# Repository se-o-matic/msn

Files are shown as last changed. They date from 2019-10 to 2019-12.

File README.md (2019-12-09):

# MSN

## MySensors Nodes
Hardware and software for MySensors.org IOT network.
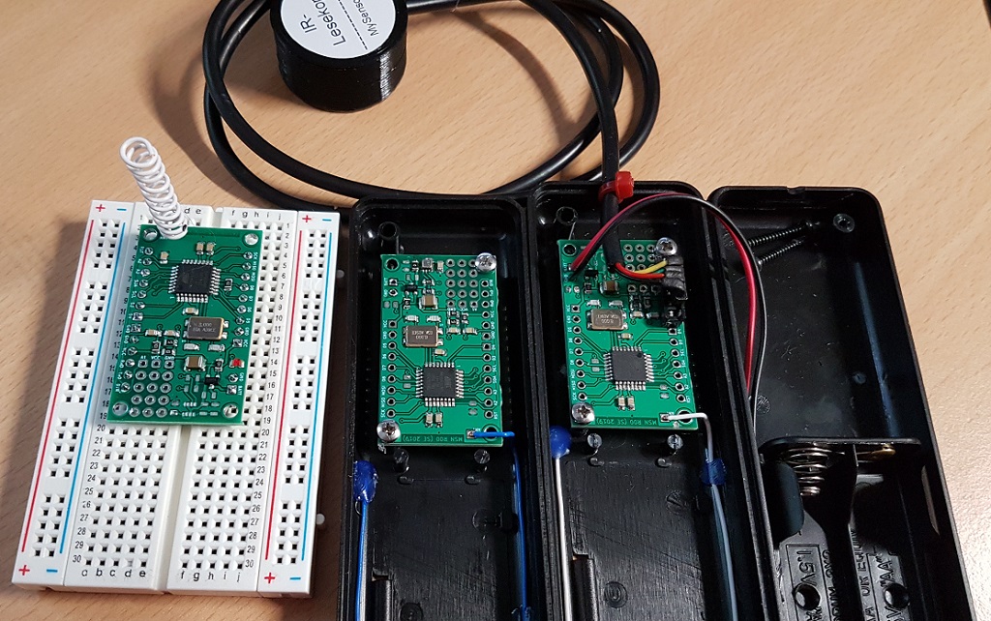
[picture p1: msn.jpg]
Different MSN sensor nodes

The MSN PCB can be used for different node types. The minimal assembly consists of a Mega328P microcontroller (as seen on many Arduinos), a RFM69CW rf module with 868 or 433 MHz and some little stuff for reverse protection and battery monitoring.

With different assembly options, this PCB can be used for:
  * Temperature, humidity and pressure measurements (With BME280 assembled)
  * Sensor above with additional light level (with extra BH1750 on the proto field)
  * Cheap temperature measurement (With DS18B20 assembled on the small proto field)
  * IR-reader for digital Power meter (with external IR Head connected to UART)
  * Prototyping on Breadboards with soldered pin header

The PCB features also
  * ISP pins are connected to the pin header for flashing the bootloader
  * Arduino pro mini compatible pin header for connecting a UART-board
  * Optional LED for example for active transmission
  * Mounting holes for fitting in the “Strapubox 6090” case
  * A snap off proto board, which fit under or on top of the MSN PCB.

## V0.1
Software tested on breadboards. Hardware not tested, because the boards are still in production.

## V1.0
TBD Software modified to run on MSN PCB. Different improvements, like other libraries for enable power savings of the sensors.

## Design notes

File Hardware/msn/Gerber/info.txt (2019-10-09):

MSN_Gerber.zip
--------------
gerber files for elecrow.com

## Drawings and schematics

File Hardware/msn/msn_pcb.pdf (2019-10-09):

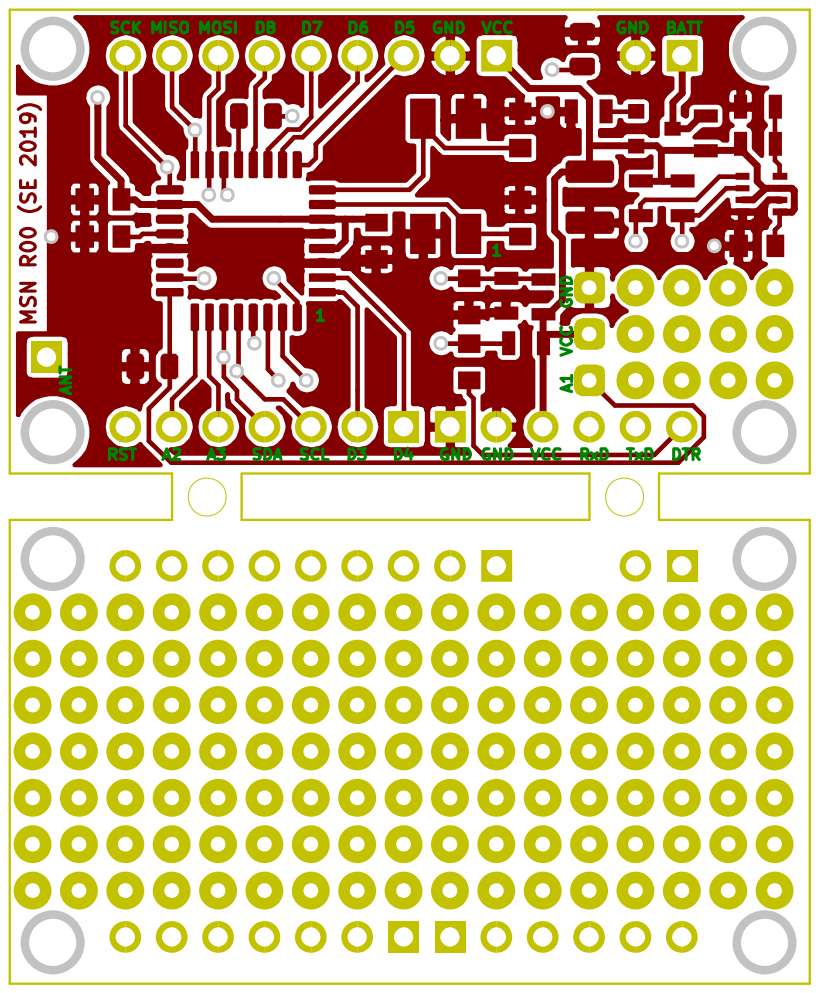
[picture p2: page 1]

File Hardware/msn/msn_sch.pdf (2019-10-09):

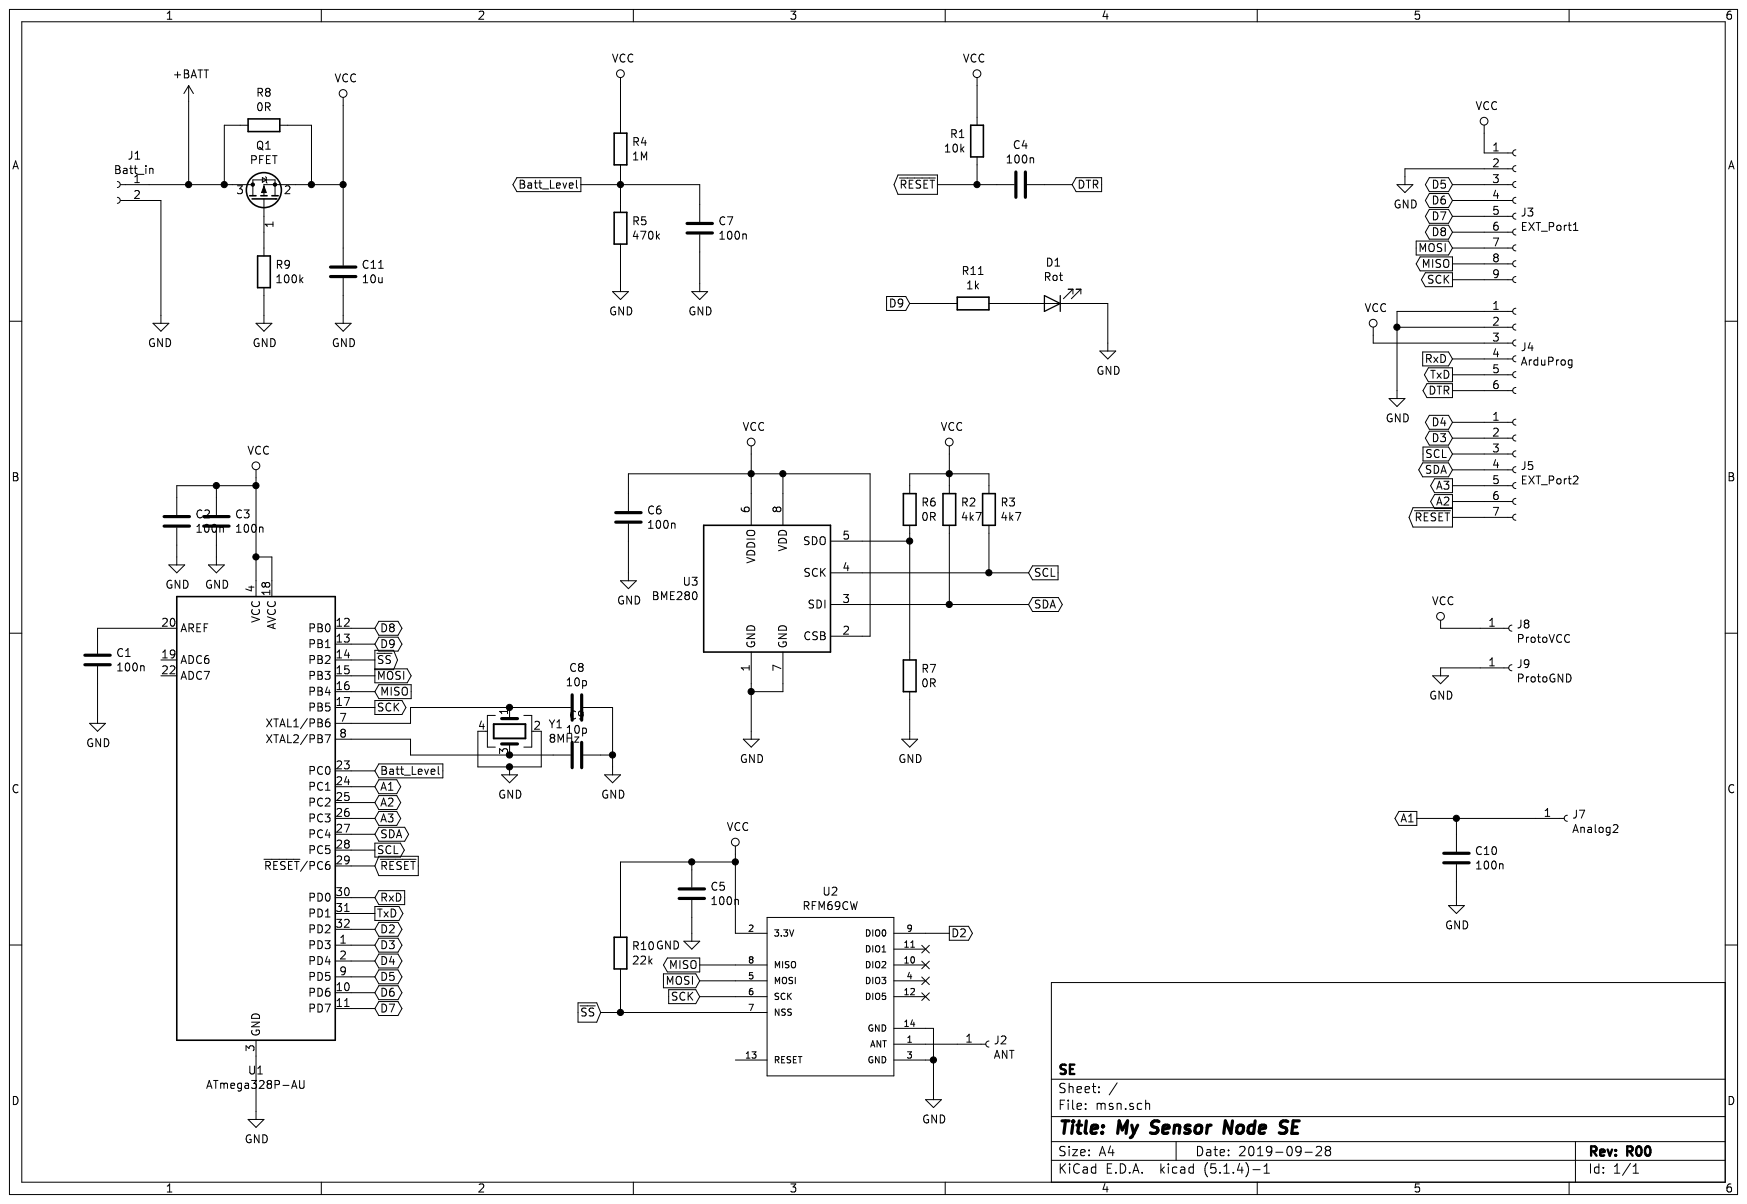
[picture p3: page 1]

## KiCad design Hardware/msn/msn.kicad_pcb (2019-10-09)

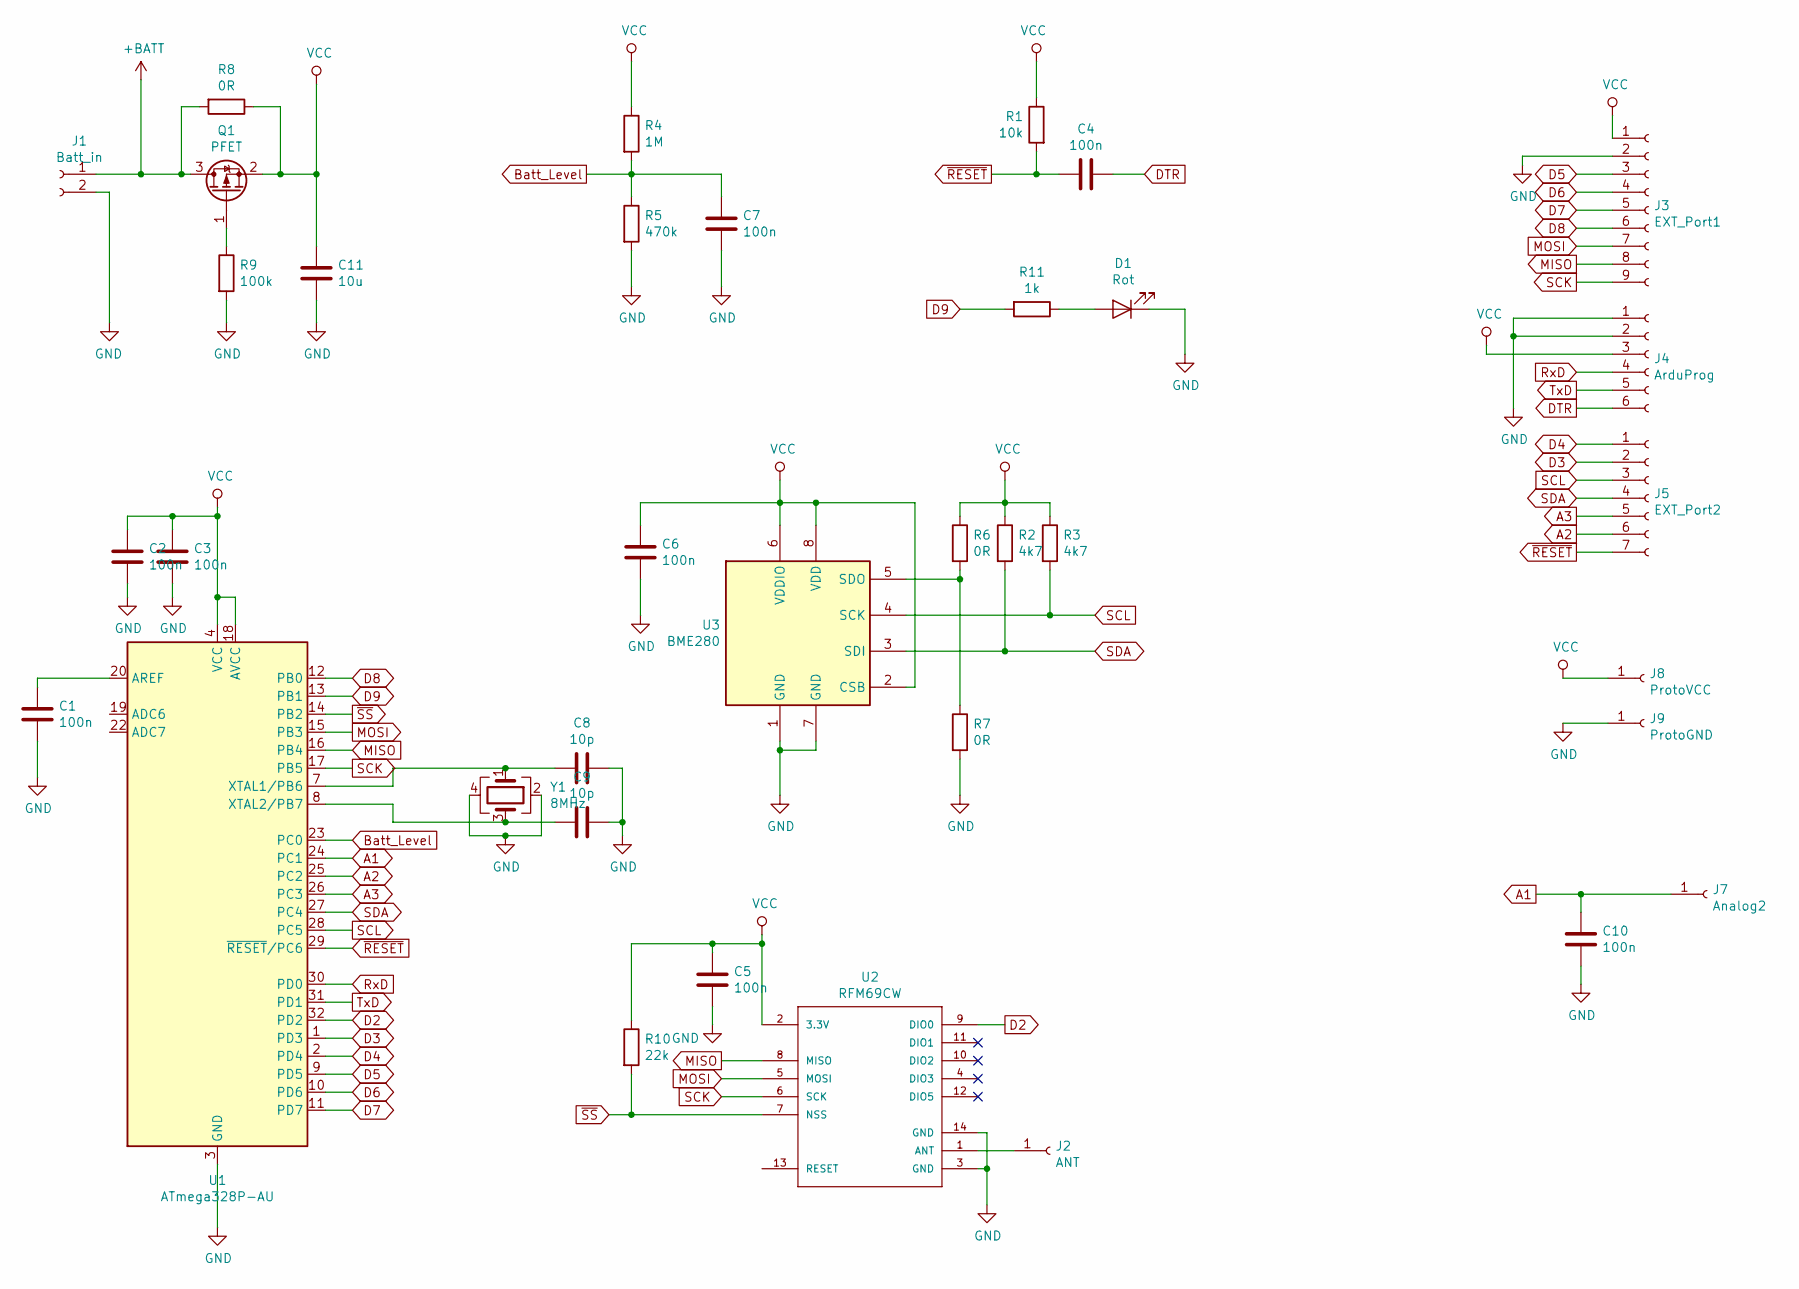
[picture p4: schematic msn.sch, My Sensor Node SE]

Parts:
C1, C2, C3, C4, C5, C6, C7, C10: 100n; C_0805_2012Metric
C8, C9: 10p; C_0805_2012Metric
C11: 10u; C_1210_3225Metric
D1: Rot; LED_0805_2012Metric
J1: Batt_in; Pin_Header_Straight_1x02_Pitch2.54mm
J2: ANT; Pin_Header_Straight_1x01_Pitch2.54mm
J3: EXT_Port1; PinHeader_1x09_P2.54mm_Vertical
J4: ArduProg; PinHeader_1x06_P2.54mm_Vertical
J5: EXT_Port2; PinHeader_1x07_P2.54mm_Vertical
J7: Analog2; PinHeader_1x01_P2.54mm_Vertical
J8: ProtoVCC; PinHeader_1x01_P2.54mm_Vertical
J9: ProtoGND; PinHeader_1x01_P2.54mm_Vertical
Q1: PFET; SOT-23
R1: 10k; R_0805_2012Metric
R2, R3: 4k7; R_0805_2012Metric
R4: 1M; R_0805_2012Metric
R5: 470k; R_0805_2012Metric
R6, R7, R8: 0R; R_0805_2012Metric
R9: 100k; R_0805_2012Metric
R10: 22k; R_0805_2012Metric
R11: 1k; R_0805_2012Metric
U1: ATmega328P-AU; LQFP-32_7x7mm_P0.8mm
U2: RFM69CW; RFM69CW-XXXS2
U3: BME280; Bosch_LGA-8_2.5x2.5mm_P0.65mm_ClockwisePinNumbering
Y1: 8MHz; Crystal_SMD_EuroQuartz_MQ-4pin_7.0x5.0mm

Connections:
+BATT: J1.1, Q1.3 (D), R8.2
A1: C10.1, J7.1, U1.24 (PC1)
A2: J5.6, U1.25 (PC2)
A3: J5.5, U1.26 (PC3)
Batt_Level: C7.1, R4.2, R5.1, U1.23 (PC0)
D2: U1.32 (PD2), U2.9 (DIO0)
D3: J5.2, U1.1 (PD3)
D4: J5.1, U1.2 (PD4)
D5: J3.3, U1.9 (PD5)
D6: J3.4, U1.10 (PD6)
D7: J3.5, U1.11 (PD7)
D8: J3.6, U1.12 (PB0)
D9: R11.2, U1.13 (PB1)
DTR: C4.2, J4.6
GND: C1.2, C2.2, C3.2, C5.2, C6.2, C7.2, C8.1, C9.1, C10.2, C11.2, D1.1 (K), J1.2, J3.2, J4.1, J4.2, J9.1, R5.2, R7.2, R9.2, U1.3 (GND), U1.5 (GND), U1.21 (GND), U2.3 (GND), U2.14 (GND), U3.1 (GND), U3.7 (GND), Y1.2, Y1.4
MISO: J3.8, U1.16 (PB4), U2.8 (MISO)
MOSI: J3.7, U1.15 (PB3), U2.5 (MOSI)
unnamed: C1.1, U1.20 (AREF)
unnamed: C8.2, U1.7 (XTAL1/PB6), Y1.1
unnamed: C9.2, U1.8 (XTAL2/PB7), Y1.3
unnamed: D1.2 (A), R11.1
unnamed: J2.1, U2.1 (ANT)
unnamed: Q1.1 (G), R9.1
unnamed: R6.2, R7.1, U3.5 (SDO)
RxD: J4.4, U1.30 (PD0)
SCK: J3.9, U1.17 (PB5), U2.6 (SCK)
SCL: J5.3, R3.2, U1.28 (PC5), U3.4 (SCK)
SDA: J5.4, R2.2, U1.27 (PC4), U3.3 (SDI)
TxD: J4.5, U1.31 (PD1)
VCC: C2.1, C3.1, C5.1, C6.1, C11.1, J3.1, J4.3, J8.1, Q1.2 (S), R1.1, R2.1, R3.1, R4.1, R6.1, R8.1, R10.1, U1.4 (VCC), U1.6 (VCC), U1.18 (AVCC), U2.2 (3.3V), U3.2 (CSB), U3.6 (VDDIO), U3.8 (VDD)
~RESET: C4.1, J5.7, R1.2, U1.29 (~RESET~/PC6)
~SS: R10.2, U1.14 (PB2), U2.7 (NSS)

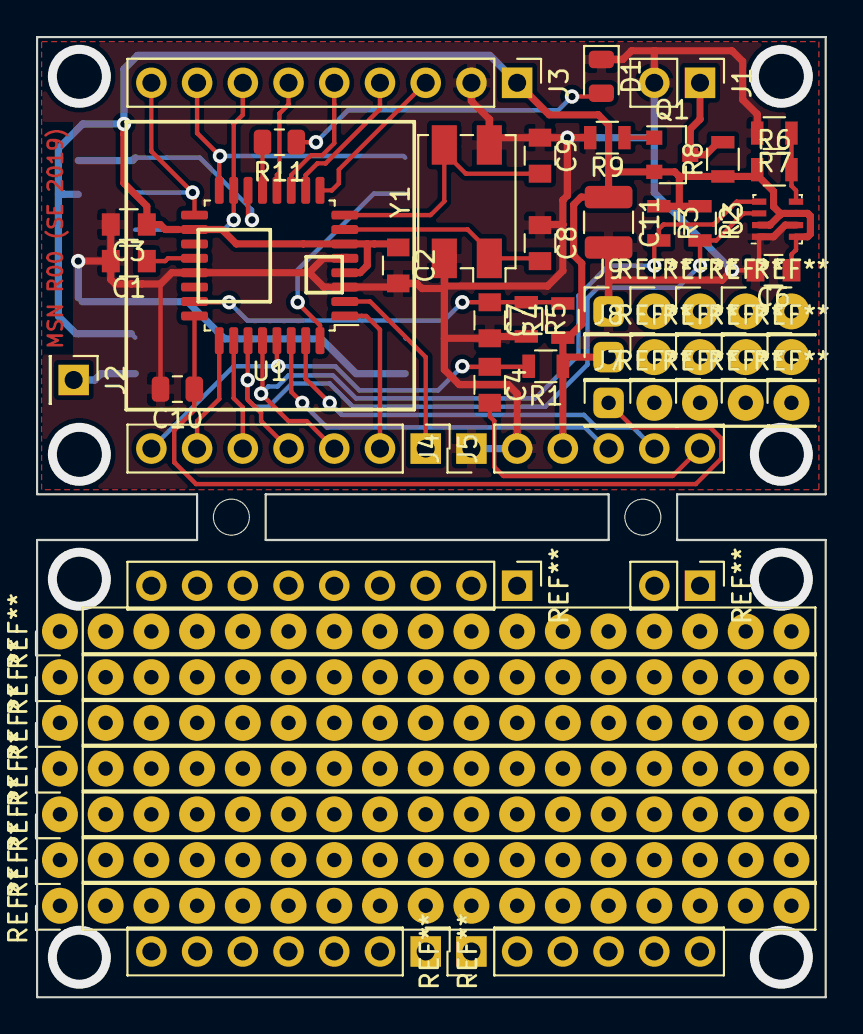
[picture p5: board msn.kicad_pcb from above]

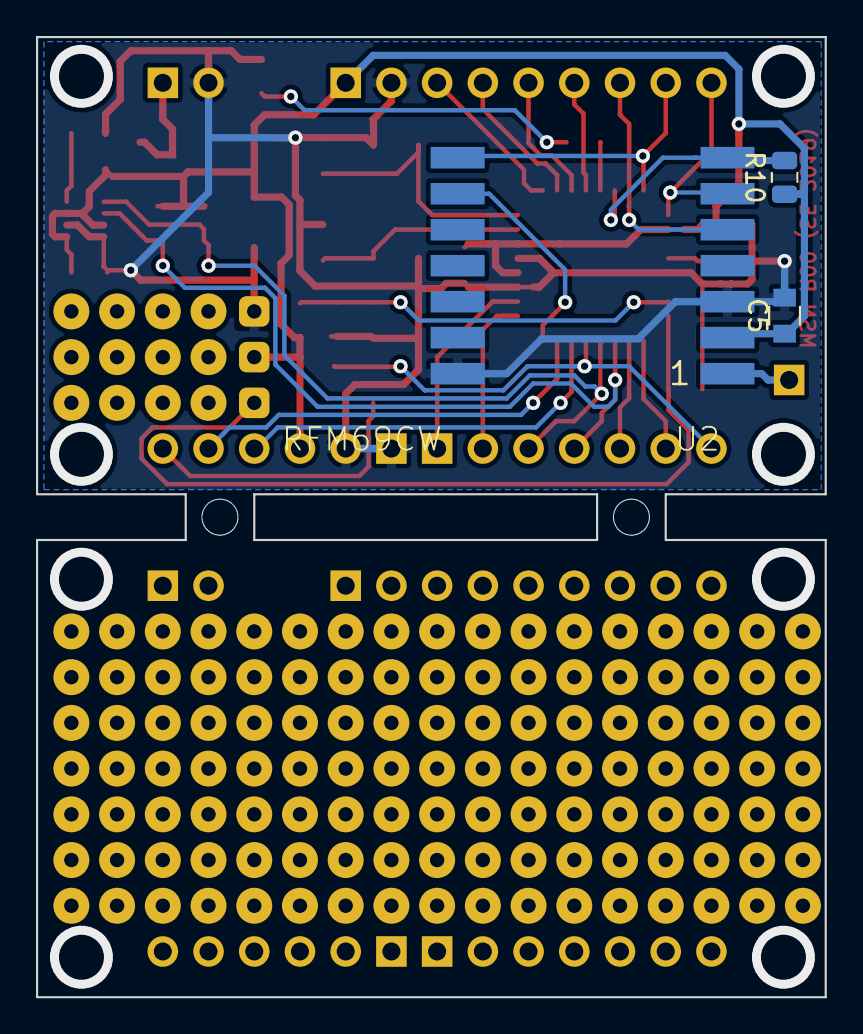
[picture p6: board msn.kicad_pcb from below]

Board: 2 copper layers, 43.8 x 53.3 mm, 36 parts (3 on the bottom side), 32 nets.

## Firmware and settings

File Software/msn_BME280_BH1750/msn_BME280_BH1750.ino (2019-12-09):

/*
 * My Sensors Node for temperature, humidity and light level
 * 
 * Hardware: MSN R00
 * BME280 (temp, hum) at I2C
 * BH1750 (light level) at I2C
 * 
 * Runs at 2 x AA batterys
 * 
 */

// RFM69CW at 433 MHz / Raspebrry Pi as ethernet gateway
#define MY_RADIO_RFM69
#define MY_RFM69_NEW_DRIVER
#define MY_RFM69_FREQUENCY RFM69_433MHZ 
#include <MySensors.h>

// BME280 library from Adafruit, need the Adafruit "Unified Sensor library", too
#include <Adafruit_BME280.h>
// BH1750 library from https://github.com/claws/BH1750
#include "BH1750.h"

// Define child IDs and messages
#define CHILD_ID_TEMP  0
#define CHILD_ID_HUM   1
#define CHILD_ID_LUX   2
MyMessage msgTemp(CHILD_ID_TEMP, V_TEMP);
MyMessage msgHum(CHILD_ID_HUM, V_HUM);
MyMessage msgLux(CHILD_ID_LUX, V_LEVEL);

// Define strings, which are send to the controller
#define SKETCHSTR "Temp Humidity LUX Sensor"
#define SKETCHVER "1.0"

// Sleep time for sensor 
uint32_t SLEEP_TIME = 300000;    // sleep time between reads (seconds * 1000 milliseconds)

// Constructor for sensors
Adafruit_BME280 bme;
#define BME280_TEMP_OFFSET -1.0    // calibration ofsset for the temperature
BH1750 bh1750;

// Battery stuff
#define EMPTY 536         // Brown Out ATMega   //536 equal to 1.8 V
#define SCALE 0.2415      // (100/950-EMPTY)    //950 equal to 3.2 V
int BATTERY_SENSE_PIN = A0;   // select the input pin for the battery sense point
int batteryPcnt = 0, oldBatteryPcnt = 0;

// Global variables for sensor values
float temp = 25.0, hum = 50.0;
float temp_last = 0.0, hum_last = 0.0;
float lux = 100, lux_last = 0;

// Helper for calculate battery percentage
int calc_pcnt(int value){
  int batteryPcnt = ((value - EMPTY) * SCALE);
  batteryPcnt = (batteryPcnt > 100) ? 100 : batteryPcnt;
  batteryPcnt = (batteryPcnt < 0) ? 0 : batteryPcnt;
  return batteryPcnt;
}

void setup() {
  // use the 1.1 V internal reference
  analogReference(INTERNAL);

  bh1750.begin(BH1750::ONE_TIME_HIGH_RES_MODE);

  //BME280 stuff
  bme.begin(0x77, &Wire);    //0x76 for break out board, 0x77 for MSN_R00
  bme.setSampling(Adafruit_BME280::MODE_FORCED,
                  Adafruit_BME280::SAMPLING_X1,   // temperature
                  Adafruit_BME280::SAMPLING_NONE, // pressure
                  Adafruit_BME280::SAMPLING_X1,   // humidity
                  Adafruit_BME280::FILTER_OFF );

  oldBatteryPcnt = calc_pcnt(analogRead(BATTERY_SENSE_PIN));
}

void presentation()
{
  // Send the sketch version information to the gateway and Controller
  sendSketchInfo(SKETCHSTR, SKETCHVER);
 
  present(CHILD_ID_TEMP, S_TEMP, "Temperature");
  present(CHILD_ID_HUM, S_HUM, "Humidity");
  present(CHILD_ID_LUX, S_LIGHT_LEVEL, "Lux");
}

void loop() {
  //read temp and hum and lux
  bme.takeForcedMeasurement();
  temp = bme.readTemperature();
  temp = temp + BME280_TEMP_OFFSET;
  hum = bme.readHumidity();

  lux = bh1750.readLightLevel();

  if(temp != temp_last){
    send(msgTemp.set(temp, 2));
    temp_last = temp;
  }
  if(hum != hum_last){
    send(msgHum.set(hum, 2));
    hum_last = hum;
  }
  if(lux != lux_last){
    send(msgLux.set(lux, 2));
    lux_last = lux;
  }

  // send the battery level
  batteryPcnt = calc_pcnt(analogRead(BATTERY_SENSE_PIN));
  if (batteryPcnt < oldBatteryPcnt) {
      sendBatteryLevel(batteryPcnt);
      oldBatteryPcnt = batteryPcnt;
  }
 
  sleep(SLEEP_TIME);
}

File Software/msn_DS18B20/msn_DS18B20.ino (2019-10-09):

/*
 * The MySensors Arduino library handles the wireless radio link and protocol
 * between your home built sensors/actuators and HA controller of choice.
 * The sensors forms a self healing radio network with optional repeaters. Each
 * repeater and gateway builds a routing tables in EEPROM which keeps track of the
 * network topology allowing messages to be routed to nodes.
 *
 * Created by Henrik Ekblad <henrik.ekblad@mysensors.org>
 * Copyright (C) 2013-2018 Sensnology AB
 * Full contributor list: https://github.com/mysensors/MySensors/graphs/contributors
 *
 * Documentation: http://www.mysensors.org
 * Support Forum: http://forum.mysensors.org
 *
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
 *******************************
 *
 * DESCRIPTION
 *
 * This is an example that demonstrates how to report the battery level for a sensor
 * Instructions for measuring battery capacity on A0 are available here:
 * http://www.mysensors.org/build/battery
 *
 */

// Enable debug prints to serial monitor
//#define MY_DEBUG

// Enable and select radio type attached
//#define MY_RADIO_RF24
//#define MY_RADIO_NRF5_ESB
#define MY_RADIO_RFM69
//#define MY_RADIO_RFM95

// Nötig bei Raspi als Gateway
#define MY_RFM69_NEW_DRIVER
#define MY_RFM69_FREQUENCY RFM69_433MHZ

#include <MySensors.h>  
#include <DallasTemperature.h>
#include <OneWire.h>

#define SKETCHSTR "Temperature Sensor"
#define SKETCHVER "0.1"

#define COMPARE_TEMP 0 // Send temperature only if changed? 1 = Yes 0 = No

#define ONE_WIRE_BUS 15 // Pin where dallase sensor is connected 
#define MAX_ATTACHED_DS18B20 16
unsigned long SLEEP_TIME = 300000; // Sleep time between reads (in milliseconds)
OneWire oneWire(ONE_WIRE_BUS); // Setup a oneWire instance to communicate with any OneWire devices (not just Maxim/Dallas temperature ICs)
DallasTemperature sensors(&oneWire); // Pass the oneWire reference to Dallas Temperature. 
float lastTemperature[MAX_ATTACHED_DS18B20];
int numSensors=0;
bool receivedConfig = false;
bool metric = true;
// Initialize temperature message
MyMessage msg(0,V_TEMP);

int BATTERY_SENSE_PIN = A0;  // select the input pin for the battery sense point
#define EMPTY 536         // Brown Out ATMega   //536 entspricht 1.8 V
#define SCALE 0.2415      // (100/950-EMPTY)    //950 entspricht 3.2 V
int batteryPcnt = 0;
int oldBatteryPcnt = 0;

int calc_pcnt(int value){
  int batteryPcnt = ((value - EMPTY) * SCALE);
  batteryPcnt = (batteryPcnt > 100) ? 100 : batteryPcnt;
  batteryPcnt = (batteryPcnt < 0) ? 0 : batteryPcnt;
  return batteryPcnt;
}

void before()
{
  // Startup up the OneWire library
  sensors.begin();
}

void setup()  
{ 
  // requestTemperatures() will not block current thread
  sensors.setWaitForConversion(false);
  analogReference(INTERNAL);
}

void presentation() {
  // Send the sketch version information to the gateway and Controller
  sendSketchInfo(SKETCHSTR, SKETCHVER);

  // Fetch the number of attached temperature sensors  
  numSensors = sensors.getDeviceCount();

  // Present all sensors to controller
  for (int i=0; i<numSensors && i<MAX_ATTACHED_DS18B20; i++) {   
     present(i, S_TEMP);
  }
}

void loop()     
{     
  // Fetch temperatures from Dallas sensors
  sensors.requestTemperatures();

  // query conversion time and sleep until conversion completed
  int16_t conversionTime = sensors.millisToWaitForConversion(sensors.getResolution());
  // sleep() call can be replaced by wait() call if node need to process incoming messages (or if node is repeater)
  sleep(conversionTime);

  // Read temperatures and send them to controller 
  for (int i=0; i<numSensors && i<MAX_ATTACHED_DS18B20; i++) {

    // Fetch and round temperature to one decimal
    float temperature = static_cast<float>(static_cast<int>((getControllerConfig().isMetric?sensors.getTempCByIndex(i):sensors.getTempFByIndex(i)) * 10.)) / 10.;

    // Only send data if temperature has changed and no error
    #if COMPARE_TEMP == 1
    if (lastTemperature[i] != temperature && temperature != -127.00 && temperature != 85.00) {
    #else
    if (temperature != -127.00 && temperature != 85.00) {
    #endif

      // Send in the new temperature
      send(msg.setSensor(i).set(temperature,1));
      // Save new temperatures for next compare
      lastTemperature[i]=temperature;
    }
  }

  // send the battery level
  batteryPcnt = calc_pcnt(analogRead(BATTERY_SENSE_PIN));
  if (oldBatteryPcnt != batteryPcnt) {
    sendBatteryLevel(batteryPcnt);
    oldBatteryPcnt = batteryPcnt;
  }

  sleep(SLEEP_TIME);
}

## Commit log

2019-10-09 Added PDF printouts
2019-12-09 Changes for running on msn pcb

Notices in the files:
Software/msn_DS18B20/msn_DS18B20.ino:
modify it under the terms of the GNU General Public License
